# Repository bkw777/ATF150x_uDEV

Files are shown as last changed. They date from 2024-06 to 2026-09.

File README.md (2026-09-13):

# ATF150x_uDEV

Tiny dev board for Atmel/Microchip ATF1502 & ATF1504 TQFP-44.

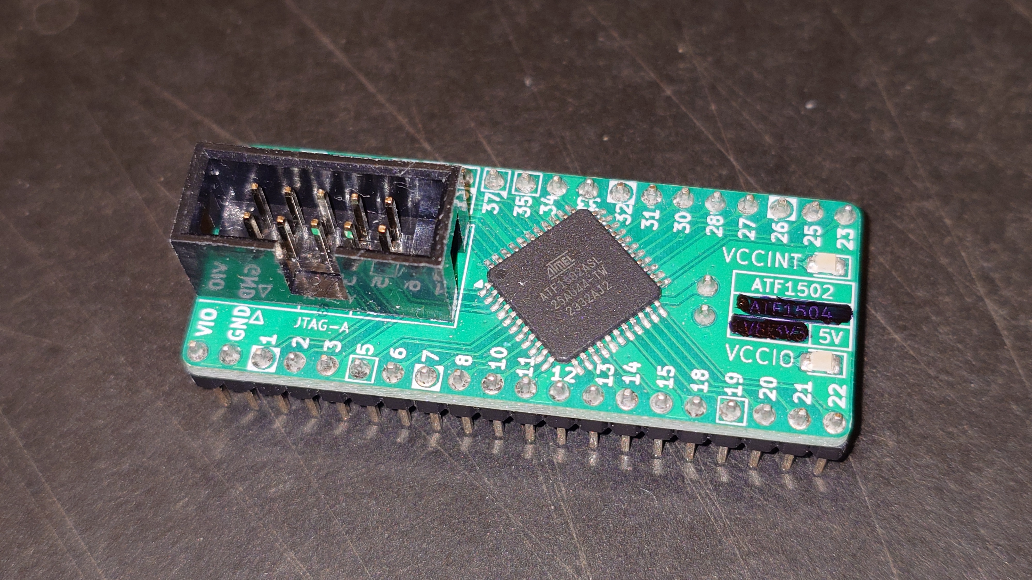
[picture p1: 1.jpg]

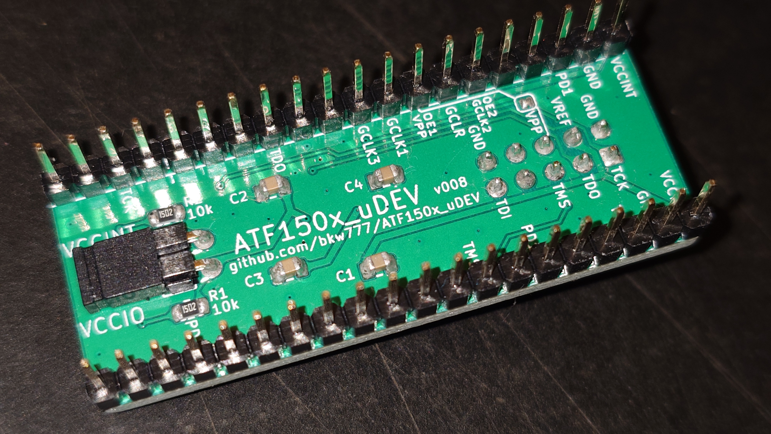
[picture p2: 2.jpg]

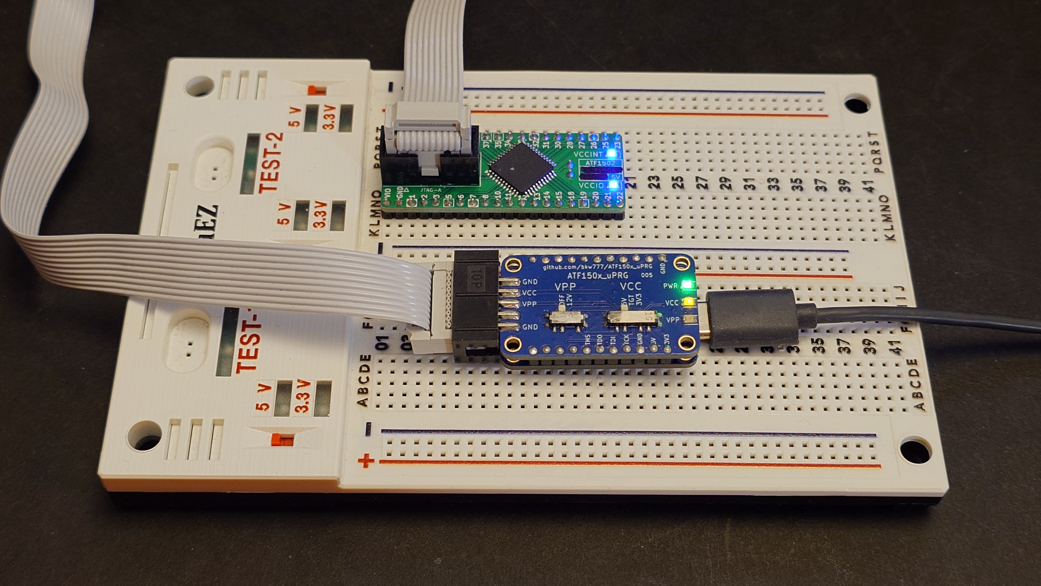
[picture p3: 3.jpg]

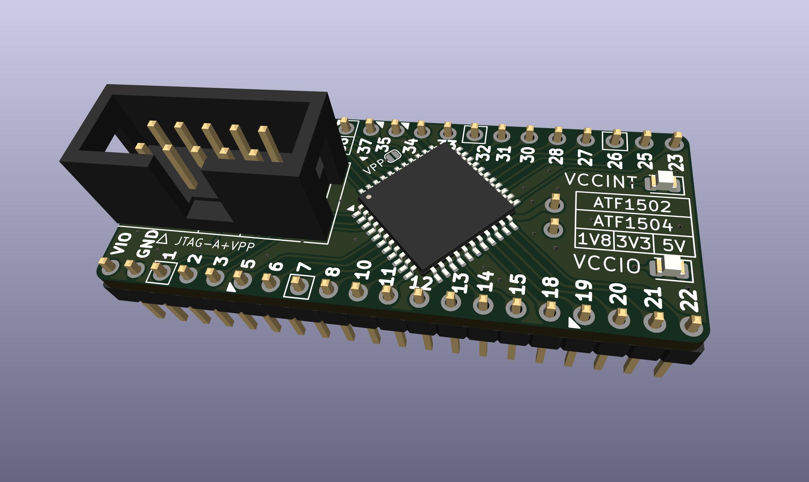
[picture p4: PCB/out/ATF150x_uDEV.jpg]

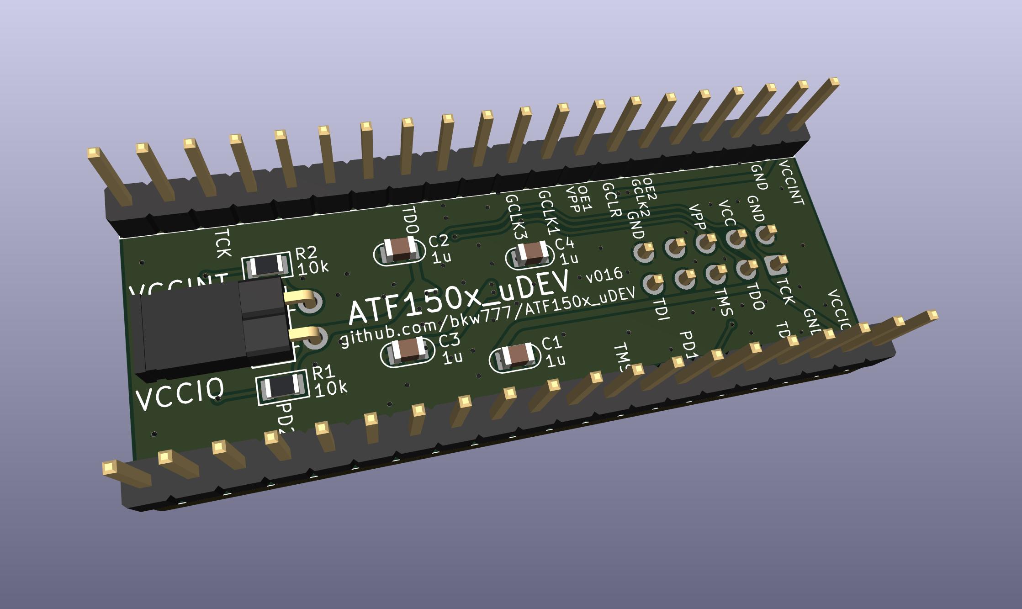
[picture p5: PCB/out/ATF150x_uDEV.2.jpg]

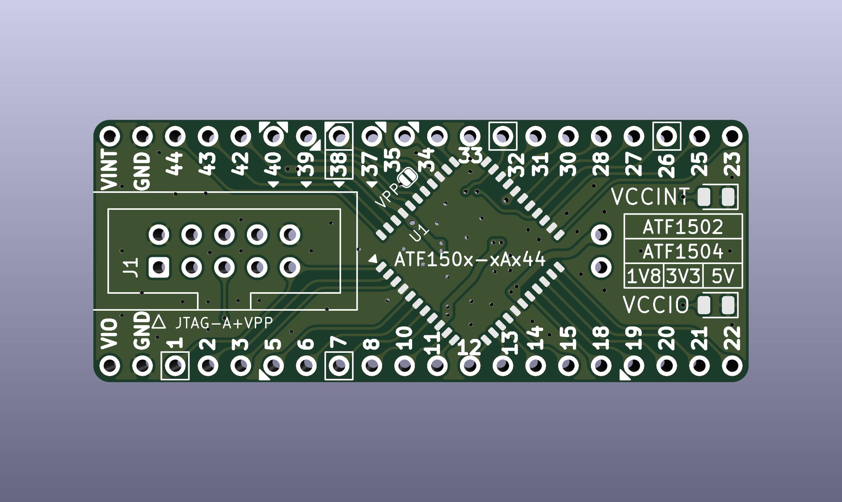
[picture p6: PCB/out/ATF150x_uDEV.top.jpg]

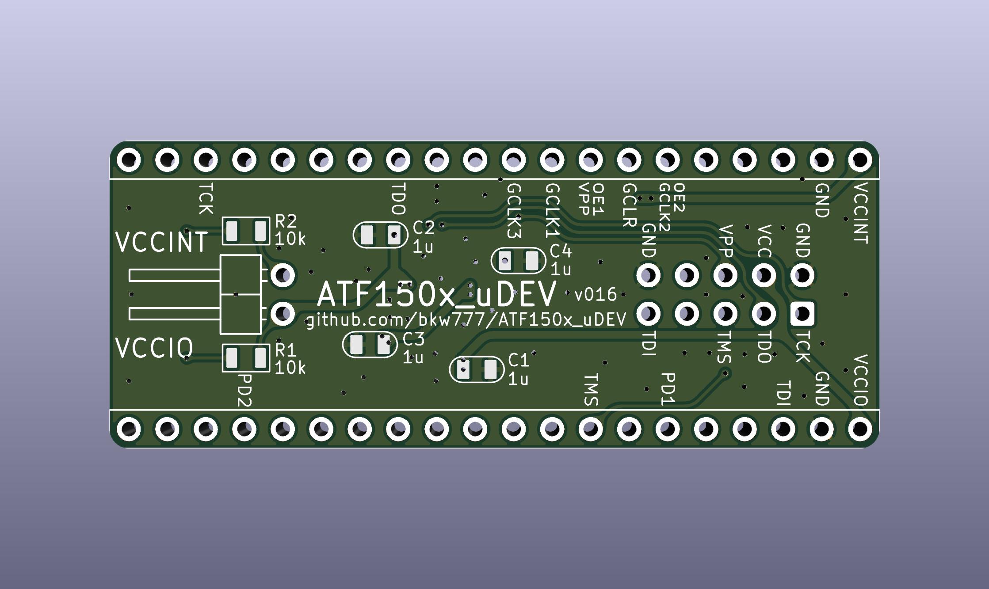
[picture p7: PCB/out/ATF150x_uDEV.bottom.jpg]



[v016 PCB at OSHPark](https://oshpark.com/shared_projects/1EtYH37r)

For C1-C4 use anything from 0.22u to 1u.

JTAG pin 6 may optionally be connected to IC pin 38 (OE1#/VPP) by the VPP solder jumper.  
[ATF150x_uPRG](https://github.com/bkw777/ATF150x_uPRG) has a matching option to output 12v VPP on JTAG pin 6.  
<!-- 
VPP is only needed if the chip is currently programmed with gateware that disables jtag.  
NOTE: VPP does NOT overcome the secure programming option!  
-->

# Programming
[Buckle Up!](programming.md)

<!--

https://github.com/hoglet67/atf15xx_yosys

https://github.com/roscopeco/atfprog-tools

https://github.com/hackup/ATF2FT232HQ

https://snowgoons.ro/posts/2020-11-25-atf15xx-vhdl-development-for-cheap/

https://www.eevblog.com/forum/fpga/atmel-atf150x-cpld-and-wincupl/

https://www.eevblog.com/forum/microcontrollers/freeopen-source-alternative-to-wincupl/

http://forum.6502.org/viewtopic.php?f=10&t=7920

dev kit
https://www.digikey.com/en/products/detail/microchip-technology/ATF15XX-DK3-U/5235981

prochip license 2 years $840
https://www.digikey.com/en/products/detail/microchip-technology/ATDS15XXKSW1/1596666

prochip cd $300 maybe just the cd same as the download? functional? not?
https://www.digikey.com/en/products/detail/microchip-technology/ATDS1500PC/524057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

-->

# Credits
Modified originally from [whitequark/ATF15xx-EVB](https://github.com/whitequark/ATF15xx-EVB)

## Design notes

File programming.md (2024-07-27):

# To program ATF150x

## Overview
References:  
https://github.com/peterzieba/5Vpld?tab=readme-ov-file#old-approach-wincupl-16v8-22v10-and-atf150x  
https://github.com/peterzieba/5Vpld/blob/main/PROGRAMMING.md#cpld-devices-atf1502-atf1504-atf1508  
https://web.archive.org/web/20080923170048/http://www.altera.com/support/kdb/solutions/rd02212005_950.html

There is no short answer, at least for the initial installation & setup.

The following only describes the WINCUPL process.  
There is also another process based on Quartus and POF2JED.

Just for basic background reference, the normal process originally would have been:  
* Install [WinCUPL and ATMISP](https://www.microchip.com/en-us/products/fpgas-and-plds/spld-cplds/pld-design-resources)  
* In WinCUPL write a `file.pld` and compile it to create a `file.jed`
* Use ATMISP to program `file.jed` to the device using a [ATDH1150USB](https://www.microchip.com/en-us/development-tool/atdh1150usb) programmer.

If you use Windows and actually have a real ATDH1150USB programmer then you can still do that.

But ATMISP only supports that one programmer and today that is over $90, even though it doesn't do anything special, it's barely any different than a $3 usb-blaster clone inside. There are no clones like for Altera USB-Blaster, Xilinx Platform Cable USB, ST-LInk etc.

And the WinCUPL gui is annoying and crashy, and doesn't do anything special. It's just a basic text editor and front-end to run `CUPL.EXE` which in turn runs `fit150*.exe`. It's most useful feature is actually just the trivial device mnemonic lookup util to provide the special code name that corresponds to your part number to put on the `Device xxxx;` line in the header of your PLD source file.

So today it's more practical to:  
* Write a [PLD file](CUPL/leds.pld) in whatever editor you like.  
* Compile it to a JED file using a [script](https://github.com/peterzieba/5Vpld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) that runs `CUPL.EXE` without the gui.  
* Use ATMISP <!-- or [fuseconv.py](https://github.com/whitequark/prjbureau/blob/main/util/fuseconv.py) -->to convert the JED to SVF.  
* Use any commmon [FT232R](https://amazon.com/dp/B0CQVB6JFV) or [FT232H](https://www.adafruit.com/product/2264) module and [openocd](https://openocd.org/) to program the device with the SVF.  

## Software Installation & Setup

These 2 workflow recipes, one for linux and one for windows, do at least make it convenient to work once the annoying install & setup is done. Follow either the Linux or Windows workflow recipes from here:
https://github.com/peterzieba/5Vpld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

A few small notes I'll add, following the linux recipe:
* I used a fresh dedicated wineprefix path just for this, not the default `~/.wine`
* I made symlinks instead of copies of `fit150*.exe`
* The directions show an `innoextract` command that extracts 5 files from the Prochip installer, but then the directions after that only explicitly mention copying the 3 `fit*.exe` files. You need to copy & overwrite all 5 extracted files.
* After running the ATMISP installer, extract `ftd2xx.dll` from the ftdi driver installer bundled with ATMISP, and place it in the same directory with `ATMISP.exe`.

Here is a start to finish install on Ubuntu 23.10.
```
$ sudo dpkg --add-architecture i386
$ sudo apt install wine wine32:i386 winetricks playonlinux innoextract openocd telnet unzip
$ mkdir ~/atf150x
$ cd ~/atf150x
$ wget https://ww1.microchip.com/downloads/en/DeviceDoc/awincupl.exe.zip
$ wget https://ww1.microchip.com/downloads/en/DeviceDoc/ATMISP7.zip 
$ wget https://ww1.microchip.com/downloads/en/DeviceDoc/ProChip5.0.1.zip
$ unzip awincupl.exe.zip
$ unzip ProChip5.0.1.zip
$ export WINEARCH=win32 WINEPREFIX=~/.wine_atmel
$ winetricks mfc40 mfc42
$ wine awincupl.exe
$ echo Supply serial number 60008009 then exit
$ wine "c:/wincupl/wincupl/wincupl.exe"
$ wine ATMISP7_setup.exe
$ unzip -jd ${WINEPREFIX}/drive_c/ATMISP7 ${WINEPREFIX}/drive_c/ATMISP7/Driver/CDM21228_Setup.exe i386/ftd2xx.dll
$ innoextract \
 -I app/Prochip/pldfit/aprim.lib \
 -I app/Prochip/pldfit/atmel.std \
 -I app/Prochip/pldfit/fit1502.exe \
 -I app/Prochip/pldfit/fit1504.exe \
 -I app/Prochip/pldfit/fit1508.exe \
 ProChip5.0.1/ProChip5_setup.exe
$ cp -f app/Prochip/pldfit/* ${WINEPREFIX}/drive_c/Wincupl/WinCupl/Fitters
$ cd ${WINEPREFIX}/drive_c/Wincupl/WinCupl/Fitters
$ ln -sf fit1502.exe find1502.exe
$ ln -sf fit1504.exe find1504.exe
$ ln -sf fit1508.exe find1508.exe
$ cd ~/.local/bin
$ wget https://github.com/peterzieba/5Vpld/raw/main/linux-workflow/5vcomp && chmod -v 755 5vcomp
$ wget https://raw.githubusercontent.com/bkw777/ATF150x_uDEV/main/bin/wine_atmel && chmod -v 755 wine_atmel
$ wget https://raw.githubusercontent.com/bkw777/ATF150x_uDEV/main/bin/cupl && chmod -v 755 cupl
$ wget https://raw.githubusercontent.com/bkw777/ATF150x_uDEV/main/bin/wincupl && chmod -v 755 wincupl
$ wget https://raw.githubusercontent.com/bkw777/ATF150x_uDEV/main/bin/atmisp && chmod -v 755 atmisp
$ wget https://raw.githubusercontent.com/bkw777/ATF150x_uDEV/main/bin/atfsvf && chmod -v 755 atfsvf
$ cd
$ rm -rf ~/atf150x
```

## Hardware

**If using an FT232R module**  
https://amazon.com/dp/B0CQVB6JFV  
https://amazon.com/dp/B0BJKCSZZW  (see note about [DTR](#DTR-vs-RTS))  
https://adafruit.com/product/284  
Wiring:  
**FT232R - JTAG**  
TXD - TCK  
RXD - TDI  
RTS - TDO  
CTS - TMS  
GND - GND  

<!--
  openocd extra config options in foo.cfg or as -c commands in the wrapper script
  https://openocd.org/doc/html/Debug-Adapter-Configuration.html

  To set the ftdi chip back to a sane state after programming
  so that the kernel can re-attach and use the module for ordinary serial uart
  without having to un-plug & re-plug
  ft232r restore_serial 0x15
-->

**If using an FT232H module**  
https://adafruit.com/product/2264  
https://amazon.com/dp/B07T9CPMHT  
https://ftdichip.com/products/um232h  
Wiring:  
**FT232H - JTAG**  
AD0 - TCK  
AD1 - TDI  
AD2 - TDO  
AD3 - TMS  
GND - GND  

In either case, if the uDEV is NOT powered, then also connect VCC to VCC and set the 3V3/5V jumper on the FTDI module to match your chip.  
AS/ASL = 5V  
ASV/ASVL = 3V3  

Optionally, [ATF150x_uPRG](https://github.com/bkw777/ATF150x_uPRG) can be combined with an FT232H module to make an ATF150x programmer with matching jtag pinout and which can also supply 12v for VPP.

##  Compile a PLD source to JED

```
$ mkdir leds
$ cd leds
$ wget https://github.com/bkw777/ATF150x_uDEV/raw/master/CUPL/leds.pld
$ cupl leds.pld
```

You should now have a file `leds.jed`

## Convert the JED to SVF

Run ATMISP:
```
$ atmisp
```

File -> New  
Number of devices: 1  
Device Name: `ATF1502ASL`  
JTAG Instruction: `Program/Verify`  
JEDEC File: `leds.jed`  
OK

[x] Write SVF File  
SVF File Name: `leds.svf`

Run  
Exit  

This should produce `leds.svf`

You can also generate an SVF file that just erases the chip back to factory state:  
Device Name: `ATF1504ASV`  
JTAG Instruction: `Erase`  
SVF File Name: `ERASE_1504ASV.svf`

There are some pre-made ERASE_xxxx.svf files included.  
ERASE_150\*AS.svf are for both AS and ASL devices.  
ERASE_150\*ASV.svf are for both ASV and ASVL devices.  

WARNING: NEVER select `JTAG Instruction: Program/Verify/Secure` unless you never want to program the chip again.  
Applying 12v to the VPP pin only overcomes the problem that the JTAG pins had been disabled by programming them for ordinary I/O, it does NOT clear the security bit. Once the security bit has been set, the chip can no longer be re-programmed by JTAG.  
[There technically still is a way to erase the chip, including the security bit, by using the parallel programming mode instead of JTAG, but it's still a manufacturer secret.](https://www.eevblog.com/forum/fpga/programming-(non-jtag)-max7000-devices/)

## Program the device with the SVF

```
$ atfsvf ft232r ATF1502ASL leds.svf
```

### DTR vs RTS
Many usb-ttl modules like [this one](https://amazon.com/dp/B0BJKCSZZW) have DTR instead of RTS on the main pin header to support resetting microcontrollers into their bootloader by DTR.

The missing RTS pin is normally used for TDO.  
To tell the ft232r driver in openocd to use the DTR pin for TDO,  
add `-c 'ft232r tdo_num 4'` to the end of the `atfsvf` command line.

Example:  
`$ atfsvf ft232r ATF1502ASL leds.svf -c 'ft232r tdo_num 4'`

reference:  
"4" is the bit number for the DTR pin in the FT232R drivers GPIO register.  
https://openocd.org/doc/html/Debug-Adapter-Configuration.html  
Scroll down to "Interface Driver: ft232r"

### VPP

If the chip was programmed with code that uses any of the JTAG pins for general I/O, then the JTAG interface becomes disabled and the chip can not be reprogrammed any more.

This can be overcome by applying 12v through a 2k2 resistor to the OE1 pin while programming.

[ATF150x_uPRG](https://github.com/bkw777/ATF150x_uPRG) is a programmer that can supply 12v on jtag pin 6, and ATF150x_uDEV can connect OE1 to jtag pin 6.

VPP does NOT overcome the security bit.  
If the chip is ever programmed with the secure option in atmisp or pof2jed, then the chip can not be reprogrammed any more.

----

# Test It

The device is now programmed with the code from `leds.pld`

Install the uDEV board in a breadboard and supply power to VCC & GND (or let the usb module supply power via the jtag connection)

Connect pins 22 & 23 to leds through 10k resistors to gnd.
PIN_22 -> LED>| -> 10K -> GND 
PIN_23 -> LED>| -> 10K -> GND 

Insert a wire in the breadboard at pin 21.

Touch the other end of the wire to vcc then gnd and back and repeat alternately.

Both LEDs change state depending on whether pin 21 is high or low.

This shows the trivial LEDS.PLD code is in effect.

----

The wrapper scripts used above:

### wine_atmel
Sets the WINEARCH & WINEPREFIX variables.  
You can source it to set your current shell environment so that wine commands use that environment by default:
```
$ . wine_atmel
$ wine explorer
```
or you can run it with arguments, and it will run those arguments in that environment without changing your current shell environment:  
`$ wine_atmel explorer`  
`$ wine_atmel cmd`  
`$ wine_atmel c:/atmisp7/atmisp.exe`  

### wincupl
Runs `WinCUPL.EXE` (gui) in the wine_atmel environment.

### cupl
Runs `CUPL.EXE` (no gui, via `5vcomp`) in the wine_atmel environment.  
`$ cupl leds.pld`

### atmisp
Runs ATMISP in the wine_atmel environment.  

The only commandline args atmisp supports are  
`atmisp.exe [filename.chn] [-1]`

`filename.chn` - Chain file that defines the type of target device, jtag operation, and jed file.

`-1` - Program the jed file without launching the gui.

Notably missing: The chain file does not include the "write svf file" setting or svf filename,  
so the -1 option can not be used to write out an svf file without the gui.  
You must manually use the gui to generate an svf file.

### atfsvf
Runs openocd with options to use a FT232R or FT232H usb-ttl module to program a ATF150x target device with an SVF file.  
Usage: `atfsvf jtag_device target_device file.svf`  
Example: `atfsvf ft232r ATF1502ASL leds.svf`

jtag_device:  
 ft232r  
 ft232h

target_device:  
 ATF1502AS  
 ATF1502ASL  
 ATF1502ASV  
 ATF1502ASVL  
 ATF1504AS  
 ATF1504ASL  
 ATF1504ASV  
 ATF1504ASVL  
 ATF1508AS  
 ATF1508ASL  
 ATF1508ASV  
 ATF1508ASVL

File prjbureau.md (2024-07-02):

# prjbureau / fuseconv.py

Alternative to ATMISP to generate SVF from JED

This is incomplete and not useful yet, just the upstream repo doesn't explain anything so I'm writing notes here.

```
git clone git@github.com:whitequark/prjbureau.git
cd prjbureau
sudo apt install yosys python3-sphinx python3-sphinx-rtd-theme python3-sphinx-argparse python3-bitarray
sh bootstrap.sh
```

This runs for a looooong time even on a i7-1280P with 64G ddr4  
Most of that seems to be generating html files under /doc

No idea if it works yet because the way it's written is not portable to use outside of the source tree.

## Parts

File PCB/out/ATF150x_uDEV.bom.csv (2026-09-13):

Reference | Value | Datasheet | Footprint | Qty | DNP
C1,C2,C3,C4 | 1u | datasheets/MLCC_2512.pdf | 000_LOCAL:C_0805 | 4
J1 | Altera JTAG-A+VPP | datasheets/JTAG-A.pdf | 000_LOCAL:IDC-Header_2x05_P2.54mm_Vertical | 1
J2,J3 | 1x20x2.54mm | ~ | 000_LOCAL:PinHeader_1x20_P2.54mm_Vertical | 2
JP1 | VCC | ~ | 000_LOCAL:PinHeader_1x02_P2.54mm_Horizontal | 1
LED1,LED2 | GRN | datasheets/LG_R971.pdf | 000_LOCAL:LED_0805 | 2
R1,R2 | 10k | datasheets/SEI-RMCF_RMCP.pdf | 000_LOCAL:R_0805 | 2
U1 | ATF150x-xAx44 | datasheets/ATF1502AS.pdf | 000_LOCAL:VQFP44 | 1

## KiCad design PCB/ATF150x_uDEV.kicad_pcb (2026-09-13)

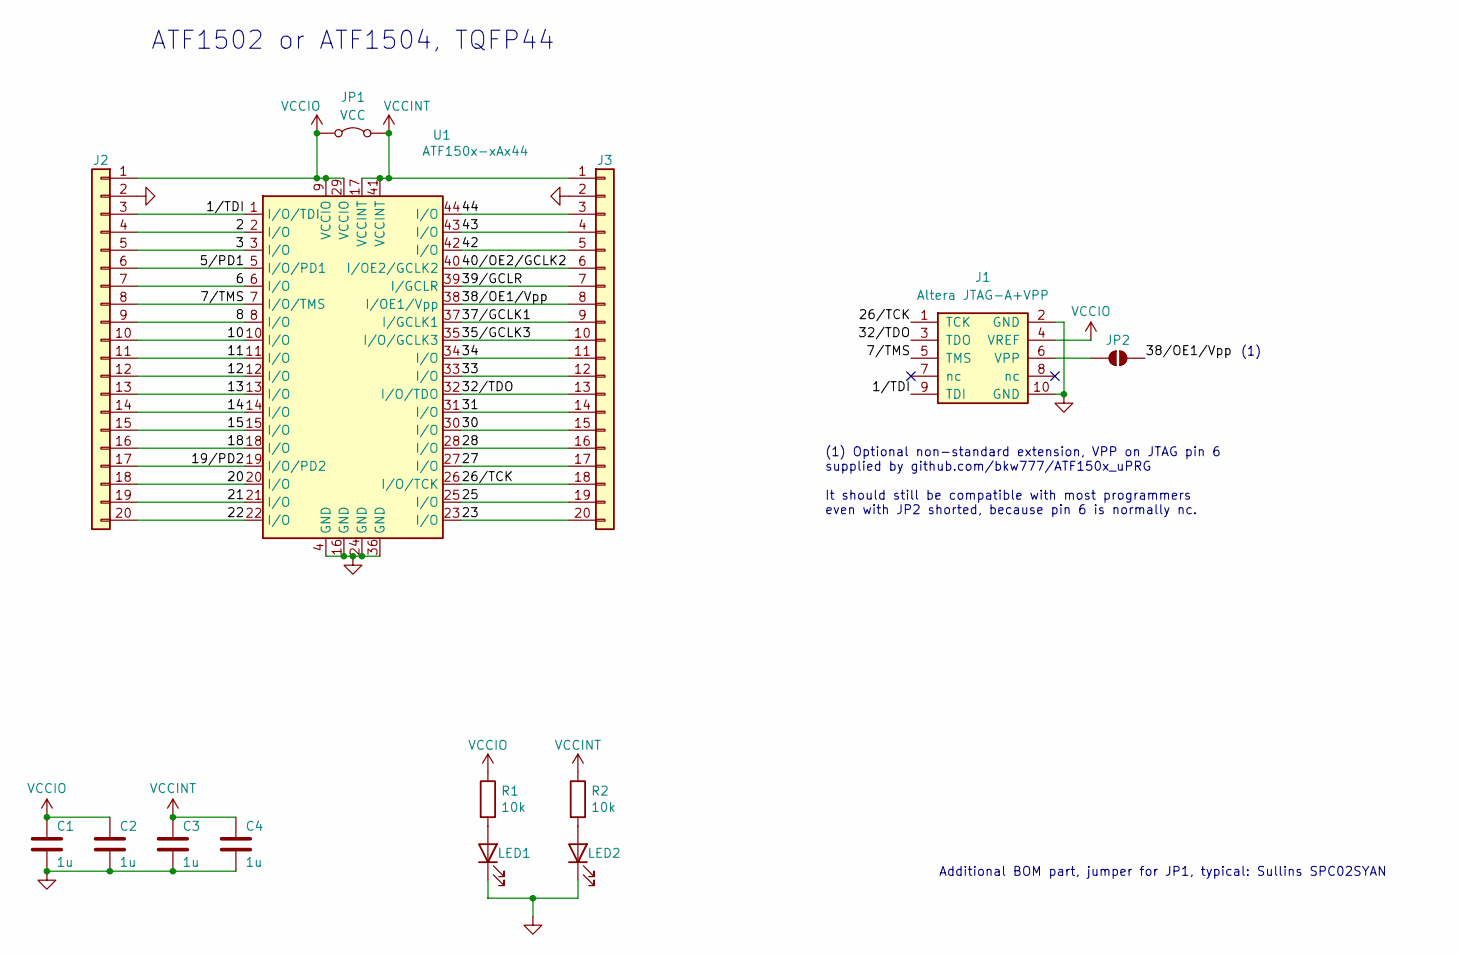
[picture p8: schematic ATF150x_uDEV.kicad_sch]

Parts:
C1, C2, C3, C4: 1u; C_0805; MPN CL21B105KOFNNWE
J1: Altera JTAG-A+VPP; IDC-Header_2x05_P2.54mm_Vertical; MPN SBH11-PBPC-D05-ST-BK
J2, J3: 1x20x2.54mm; PinHeader_1x20_P2.54mm_Vertical; MPN PRPC020SAAN-RC
JP1: VCC; PinHeader_1x02_P2.54mm_Horizontal; MPN PRPC002SBBN-M71RC
JP2: VPP; SolderJumper_1mm_2p_open
LED1, LED2: GRN; LED_0805; MPN LG_R971-KN-1-0-20-R18
R1, R2: 10k; R_0805; MPN RMCF0805FT10K0
U1: ATF150x-xAx44; VQFP44; MPN ATF1504ASL-25AU44

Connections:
/1/TDI: J1.9 (TDI), J2.3, U1.1 (I/O/TDI)
/2: J2.4, U1.2 (I/O)
/3: J2.5, U1.3 (I/O)
/5/PD1: J2.6, U1.5 (I/O/PD1)
/6: J2.7, U1.6 (I/O)
/7/TMS: J1.5 (TMS), J2.8, U1.7 (I/O/TMS)
/8: J2.9, U1.8 (I/O)
/10: J2.10, U1.10 (I/O)
/11: J2.11, U1.11 (I/O)
/12: J2.12, U1.12 (I/O)
/13: J2.13, U1.13 (I/O)
/14: J2.14, U1.14 (I/O)
/15: J2.15, U1.15 (I/O)
/18: J2.16, U1.18 (I/O)
/19/PD2: J2.17, U1.19 (I/O/PD2)
/20: J2.18, U1.20 (I/O)
/21: J2.19, U1.21 (I/O)
/22: J2.20, U1.22 (I/O)
/23: J3.20, U1.23 (I/O)
/25: J3.19, U1.25 (I/O)
/26/TCK: J1.1 (TCK), J3.18, U1.26 (I/O/TCK)
/27: J3.17, U1.27 (I/O)
/28: J3.16, U1.28 (I/O)
/30: J3.15, U1.30 (I/O)
/31: J3.14, U1.31 (I/O)
/32/TDO: J1.3 (TDO), J3.13, U1.32 (I/O/TDO)
/33: J3.12, U1.33 (I/O)
/34: J3.11, U1.34 (I/O)
/35/GCLK3: J3.10, U1.35 (I/O/GCLK3)
/37/GCLK1: J3.9, U1.37 (I/GCLK1)
/38/OE1/Vpp: J3.8, JP2.2 (B), U1.38 (I/OE1/Vpp)
/39/GCLR: J3.7, U1.39 (I/GCLR)
/40/OE2/GCLK2: J3.6, U1.40 (I/OE2/GCLK2)
/42: J3.5, U1.42 (I/O)
/43: J3.4, U1.43 (I/O)
/44: J3.3, U1.44 (I/O)
GND: C1.2, C2.2, C3.2, C4.2, J1.2 (GND), J1.10 (GND), J2.2, J3.2, LED1.1 (K), LED2.1 (K), U1.4 (GND), U1.16 (GND), U1.24 (GND), U1.36 (GND)
unnamed: J1.6 (VPP), JP2.1 (A)
unnamed: LED1.2 (A), R1.2
unnamed: LED2.2 (A), R2.2
VCCINT: C3.1, C4.1, J3.1, JP1.2 (B), R2.1, U1.17 (VCCINT), U1.41 (VCCINT)
VCCIO: C1.1, C2.1, J1.4 (VREF), J2.1, JP1.1 (A), R1.1, U1.9 (VCCIO), U1.29 (VCCIO)

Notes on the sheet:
(1)
ATF1502 or ATF1504, TQFP44
(1) Optional non-standard extension, VPP on JTAG pin 6 supplied by github.com/bkw777/ATF150x_uPRG It should still be compatible with most programmers even with JP2 shorted, because pin 6 is normally nc.
Additional BOM part, jumper for JP1, typical: Sullins SPC02SYAN

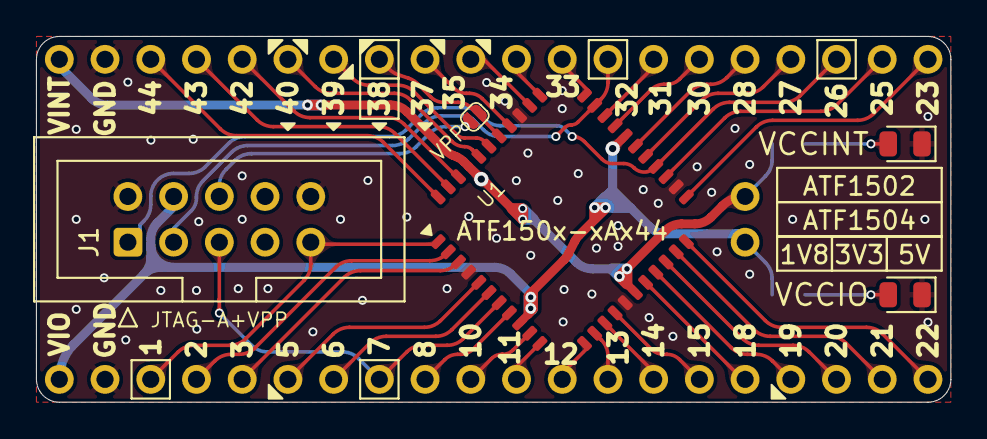
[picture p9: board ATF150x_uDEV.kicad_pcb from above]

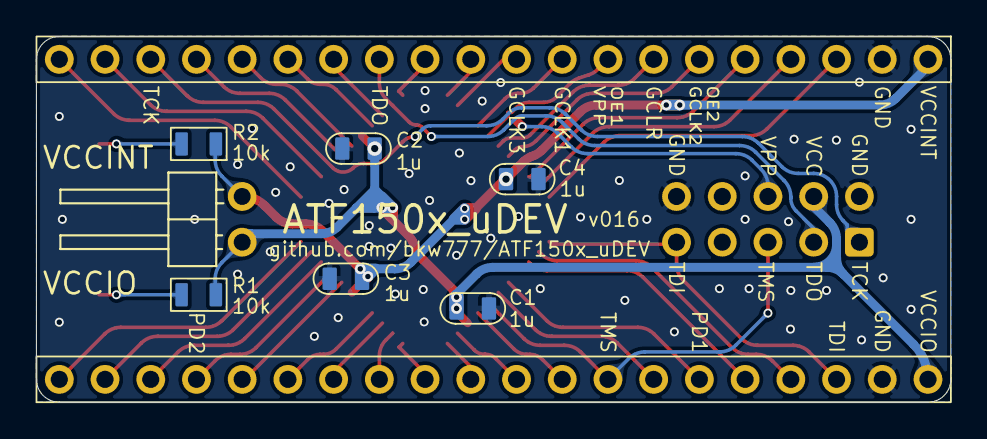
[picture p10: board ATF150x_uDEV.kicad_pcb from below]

Board: 2 copper layers, 50.8 x 20.3 mm, 14 parts (9 on the bottom side), 42 nets.

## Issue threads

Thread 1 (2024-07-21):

Secret VccIO Pins

peterzieba, 2024-07-21:
Hi,

Since you're making a dev board for the 44-pin TQFP, I figured I'd mention a little tidbit that I came across:

The bigger parts (like the ATF1504AS and the ATF1508AS in >44pin packages) have separate lines for VccIO and VccCore and so can technically be run at 3.3V IO as mentioned in their datasheets.

What isn't mentioned in the datasheet is that this is likely possible all the same for the 44-pin parts.
On the smaller 44-pin parts they simply have 4 Vcc pins in the datasheet, however, if you hit them with a voltmeter, you'll find that two are connected to eachother, and the other two are connected to eachother. I'm pretty sure the 44-pin devices are capable of running independent VccCore at 5V and VccIO at 3.3V just as well.

I have yet to test this in a circuit, but between this mystery programming adapter PDF and the ohmmeter checks, it seems likely that this would work:
http://matthieu.benoit.free.fr/all03/adp/HiLo_ADP-ATF1504.PDF

I intend to make a board that tests this theory at some point.
Cheers

bkw777, 2024-07-21:
Yeah I saw that and verified with a dmm the same way. In another project(1) I made a symbol that labels pins 9 & 29 as VCCA and  17 & 41 as VCCB, just because since they don't have continuity in the chip, I want any schematic to show, and any user to know, that these are two different nets that must both be supplied, even if they must both be supplied with the same thing.

But I haven't yet tested to see if they actually function as VCC & VCCIO.

Definitely if it checks out, meaning behaves as VCCIO and doesn't cause any obvious problems, I'll update the board to break those out.

(1) [REX_ATF](https://github.com/bkw777/REX_ATF), a version of [REX_Classic](https://github.com/bkw777/REX_Classic) but with ATF1504ASL replacing the XCR7064XL. It's actually all done. Got the vhdl to build in quartus, made new pin assignments to make pcb routing better and to reserve the jtag pins so you don't need vpp, pof2jed success, jed to svf success, ordered pcbs, built one, programmed it with openocd success... and it doesn't work :)   Prevents the machine from booting the main rom if it's connected at all.

I think it might be something with the default pin behavior. The original UCF file for the xilinx part employs internal pullups on several control pins, and I can't find any equivalent feature in quartus, at least not for max7000s. I haven't o-scoped it yet to see what's actually different between how the new design behaves vs the old. I only built it a day ago and I spent all day yesterday just getting modelsim to run and writing up yet another recipe of how to get it installed and running, this time on ubuntu 23.10. And now it's running but I don't know how to use it. :)

bkw777, 2024-07-26:
AHA!
The official manual for ATF15xx-DK3-U has a schematic that labels tqfp44 pins 9 & 29 as VCCIO and 17 & 41 as VCCINT !

https://www.microchip.com/en-us/development-tool/atf15xx-dk3-u

https://ww1.microchip.com/downloads/aemDocuments/documents/OTH/ProductDocuments/UserGuides/Atmel-8961-CPLD-ATF15xx-DK3-U-Development-Kit-UserGuide.pdf

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

bkw777, 2024-07-26:
d96517f0

Closed 2024-07-26.

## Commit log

2024-06-14 single board, silkscreen pin numbers
    [ATF1502AS_uDEV.kicad_pcb, ATF1504AS_uDEV.kicad_pcb, ATF1504AS_uDEV.kicad_sch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]
2024-06-14 shield all traces
    [ATF150xAS_uDEV.kicad_pcb]
2024-06-16 tiny alignment of fiducials
    [ATF150xAS_uDEV.kicad_pcb]
2024-06-23 fix silkscreen pin 6, remove AS from name & part number
    [ATF150x_uDEV.kicad_pcb, ATF150x_uDEV.kicad_sch]
2024-06-24 jtag symbols
    [ATF150x_uDEV.kicad_sch]
2024-06-24 add VPP to JTAG
    [ATF150x_uDEV.kicad_pcb, ATF150x_uDEV.kicad_sch]
2024-07-02 add programming software install & usage doc
    [ATF150x_uDEV.kicad_pcb, ft232h-not-needed.cfg, ft232h.cfg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]
2024-07-05 programming wrapper scripts
    [ATF150x_uDEV.kicad_pcb]
2024-07-10 atfsvf support ASV devices, ERASE_xxx.svf
    [ft232h.cfg, ft232r_xx.cfg]
2024-07-11 silkscreen touchup
    [ATF150x_uDEV.kicad_pcb]
2024-07-14 silkscreen and gnd paths
    [ATF150x_uDEV.kicad_pcb]
2024-07-26 seperate vccio vccint
    [ATF150x_uDEV.kicad_pcb, ATF150x_uDEV.kicad_sch, jumper.step]
2024-07-26 move jumper to bottom side
    [ATF150x_uDEV.kicad_pcb, ATF150x_uDEV.kicad_sch]
2024-07-26 update link in comment in sch
    [ATF150x_uDEV.kicad_sch]
2024-07-26 tiny pcb adjusts
    [ATF150x_uDEV.kicad_pcb]
2026-02-27 correct pin 44 label, silkscreen, pics, move vpp jumper
    [ATF150x_uDEV.kicad_pcb, ATF150x_uDEV.kicad_sch]
2026-03-17 pcb double vias on power traces
    [ATF150x_uDEV.kicad_pcb]
2026-09-05 fillet tracks
    [ATF150x_uDEV.kicad_pcb]
2026-09-06 fillet tracks, silkscreen, 3d models
    [ATF150x_uDEV.kicad_pcb, jumper.step]
2026-09-13 streamline traces, eliminate a via
    [ATF150x_uDEV.kicad_pcb]
2026-09-13 mpns & bom
    [ATF150x_uDEV.bom.csv, ATF150x_uDEV.kicad_pcb, ATF150x_uDEV.kicad_sch]

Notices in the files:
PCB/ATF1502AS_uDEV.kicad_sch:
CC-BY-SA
